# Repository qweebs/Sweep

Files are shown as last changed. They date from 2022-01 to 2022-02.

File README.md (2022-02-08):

# Sweep



<span>
  <a href="https://discord.gg/czXcTXbsgU">
    
  </a>
  
</span>

## What is sweep?

Sweep is a version of the more fabulous [Ferris](https://github.com/pierrechevalier83/ferris) by [Pierre Chevalier](https://github.com/pierrechevalier83/) that uses a daughter board like a promicro, elite-c, bit-c, nice!nano etc. instead of using onboard components.

## What are the different types?

| Device | Bluetooth Support<sup>[1]</sup> | On/Off Switch | Reversible PCB | Choc V1 | Choc V2 | Choc Mini | MX & Alps | Choc Spacing<sup>[2]</sup> | Tenting<sup>[3]</sup> |
| :--- | :---: | :---: | :---: | :---: | :---: | :---: | :---: | :---: | :---: |
| Sweep2.x | ✔ | ✔ | | ✔ | | | | ✔ | ✔ |
| Sweep Bling MX | ✔ | ✔ | ✔ | | | | ⚠<sup>[4]</sup> | | ✔ |
| Sweep High | ✔ | ✔ | | ✔ | ✔ | | ✔ | | ✔ |
| Sweep Half Swept  | ✔ | ✔ | ✔ | ✔ | | | | ✔ | ✔ |
| Sweep Compact Low | ✔ | | ✔ | | | ✔ | | ✔ | |

*<sup>[1]</sup> It simply means that it supports the nice!nano. An on/off switch is recommended for bluetooth*  
*<sup>[2]</sup> Choc spaced boards have the switches in a tighter grid. This provides a better final look but is only compatible with some choc keycaps (e.g. MBK)*  
*<sup>[3]</sup> Supports splitkb's [tenting puck](https://splitkb.com/products/tenting-puck?_pos=1&_psq=tenting%20&_ss=e&_v=1.0)*  
*<sup>[4]</sup> MX + kailh hotswap ONLY. Alps are NOT supported*  

* Sweep2 - Recommended Choc v1 board with all the features.
* Sweep Bling MX - An MX only Sweep that features Kailh's hotswap sockets and a stacked case.
* Sweep High - Same as the Sweep2 but trades choc spacing for compatibility with more switches and keycaps.
* Sweep Half Swept - Half of a Sweep2 with double pro-micro footprint (letting you avoid having one daughter-board flipped upside-down)
* Sweep Compact Low - The only version that supports Choc minis.

## Components list

To build and use a Sweep you will need:

* 1x PCB Kit
* 2x promicro compatible boards or 2 nice!nanos.
* 34 switches of a compatible type (refer to the compatibility table)
* 34 keycaps
* 2x reset switches (optional; [B3U-1000P(M)](https://github.com/davidphilipbarr/Sweep/issues/20))
* Some little rubber feet/bumpers
* 2x power switches (optional if supported; MSK 12C02)
* 1x TRRS (not TRS!) cable (wired build only)
* 2x TRRS Jack [PJ-320A] (wired build only)
* 1 USB Cable (depends on your micro-controller choice)

## How do I make this thing?

<a href="https://www.youtube.com/watch?v=fBPu7AyDtkM" target="_blank">
  
</a>

## Firmware

The firmware can be found [with the Ferris  firmware as part of QMK](https://github.com/qmk/qmk_firmware/tree/master/keyboards/ferris/sweep).

Firmware for zmk and bluemicro_ble is called ["Cradio"](https://zmk.dev/docs/hardware/).

## Who made this?

* [Pierre Chevalier](https://github.com/pierrechevalier83)
* [David Barr](https://github.com/davidphilipbarr)
* [Ibnu Daru Aji](https://github.com/ibnuda/)
* [Duccio](https://github.com/duckyb)

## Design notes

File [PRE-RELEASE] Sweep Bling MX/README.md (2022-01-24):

# <span style="color: #FFC400; font-weight: 600"> ⚠ WARNING! PRE-RELEASE!  ⚠</span>
## This device is currently in pre-release phase. <br> As such, it has not yet been tested and subject to changes. <br> Please keep this in mind if you wish to build it.

After being reported as functional it will receive a new stable release.

# Sweep Bling MX
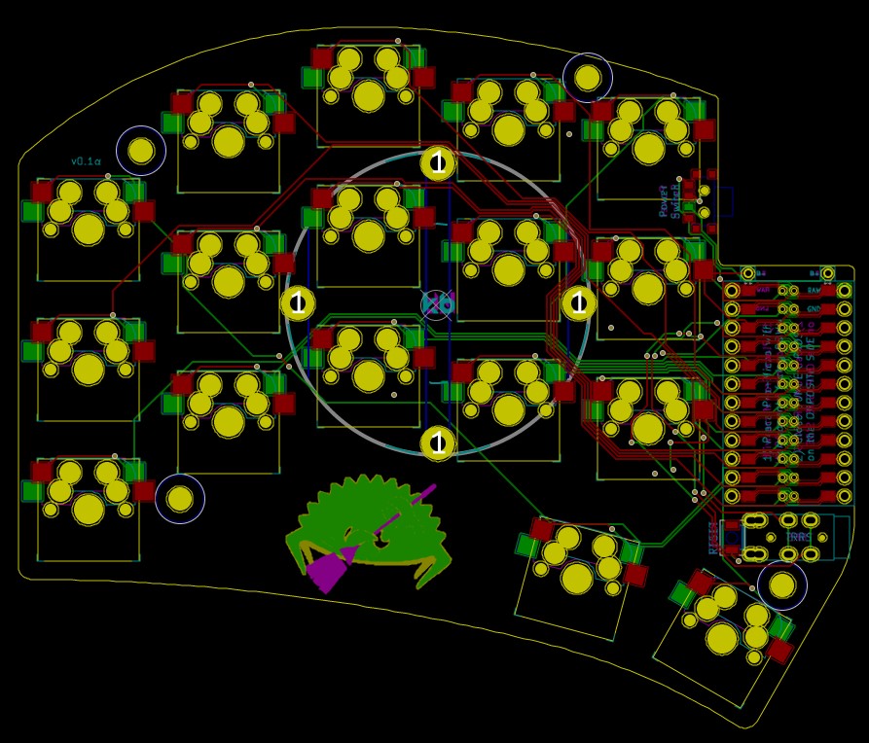
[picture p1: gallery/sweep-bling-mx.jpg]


This version of the Sweep features MX Switches support (exclusively) with hotswap sockets. As well as tenting support.

It also features mouting holes for a stacked case. You can find the switch plate and bottom plate files in the relative folders.

The bottom plate is also compatible with tenting, you can break away the middle section to allow installation of the puck.

## Ordering The PCB

To order the PCB the following settings are recommended<sup>1,2</sup>: 

|Detail|Value|
|---|---|
|Gerber file|`sweep_bling_mx_gerber.zip`|
|Base material|FR-4|
|Layers|2|
|Dimension|95.15mm x 229.54mm|
|Different design|1|
|Delivery format|Single PCB|
|PCB thickness|1.6mm|
|PCB color|(Personal preference)|
|Silkscreen|(Personal preference)|
|Surface finish|(Personal preference)|
|Outer copper weight|1oz|
|Gold Fingers|No|
|Confirm production file|No|
|Castellated holes|No|
|Remove order number|Yes|

1: Settings are for [JLCPCB](https://jlcpcb.com/), but could work for other manufacturers.

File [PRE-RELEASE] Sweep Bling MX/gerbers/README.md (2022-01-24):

| Bottom plate | PCB | Switch Plate |
| --- | --- | --- |
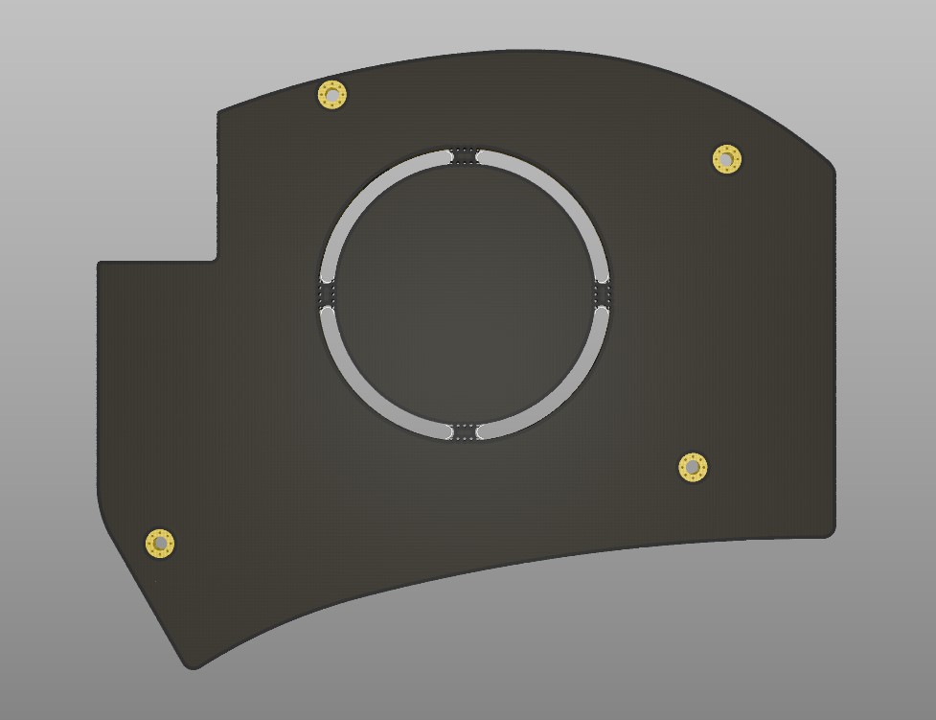
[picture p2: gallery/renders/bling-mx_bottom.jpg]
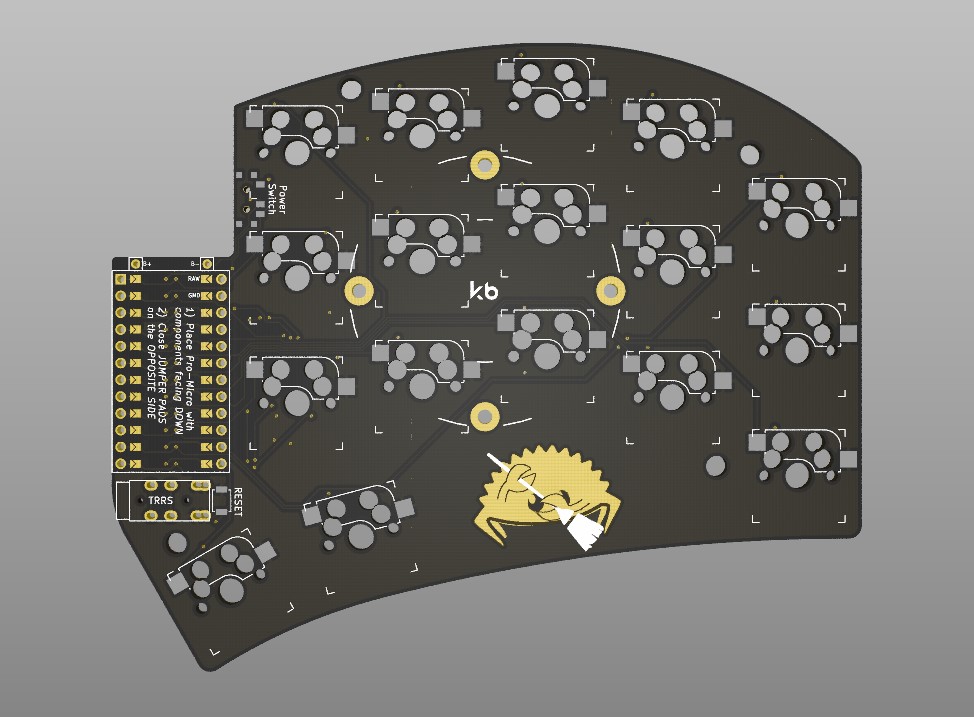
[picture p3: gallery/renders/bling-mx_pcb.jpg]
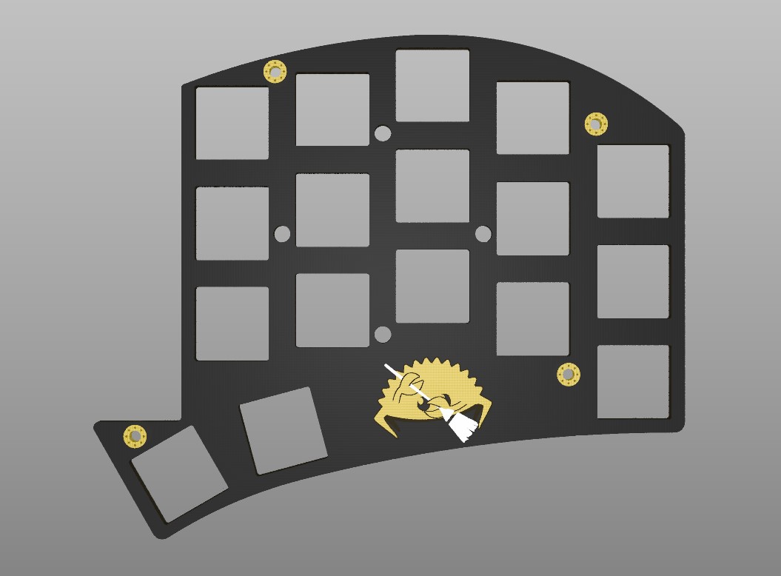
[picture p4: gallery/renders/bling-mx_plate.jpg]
|  |  |  |

# Notes:

- **DRILL TIME FEE**: When ordering PCBs with complex shapes like the switch plate and bottom plate, it is possible that the factory will ask for additional fees.

# PCB Hardware Kit (for both sides)
## Required
- 1x PCB Kit
- 2x promicro compatible boards or nice!nanos
- 34 MX switches
- 34 Kailh hotswap sockets
- 34 keycaps

### Optional:
- 2x Battery (required only for wireless; 301230 / 301228)
- 2x Power switches (recommended for wireless; MSK 12C02)
- 2x reset switches ([B3U-1000P(M)](https://github.com/davidphilipbarr/Sweep/issues/20))

# Case Hardware Kit (for both sides)

## Required:  
- 16x M2 Screws
- 8x M2 Spacers. (Max diameter: 3mm, Length: 6-8mm)
- 8-12x Silicone feet stickers

### Optional:
- 2x Splitkb tenting puck
- 2x Manfrotto MP3-BK tripods

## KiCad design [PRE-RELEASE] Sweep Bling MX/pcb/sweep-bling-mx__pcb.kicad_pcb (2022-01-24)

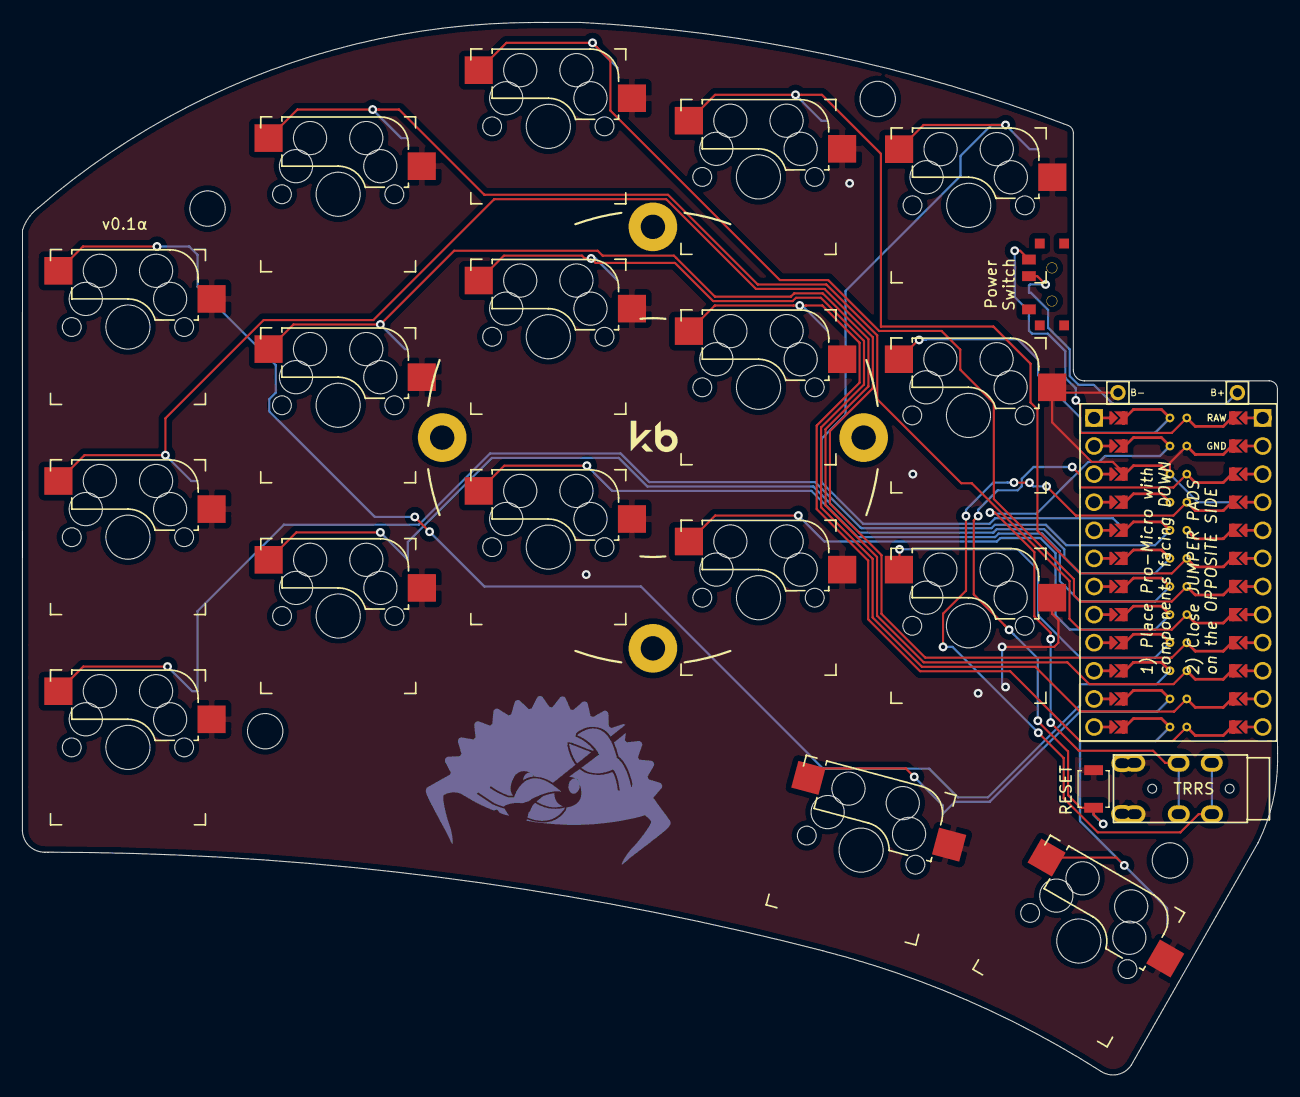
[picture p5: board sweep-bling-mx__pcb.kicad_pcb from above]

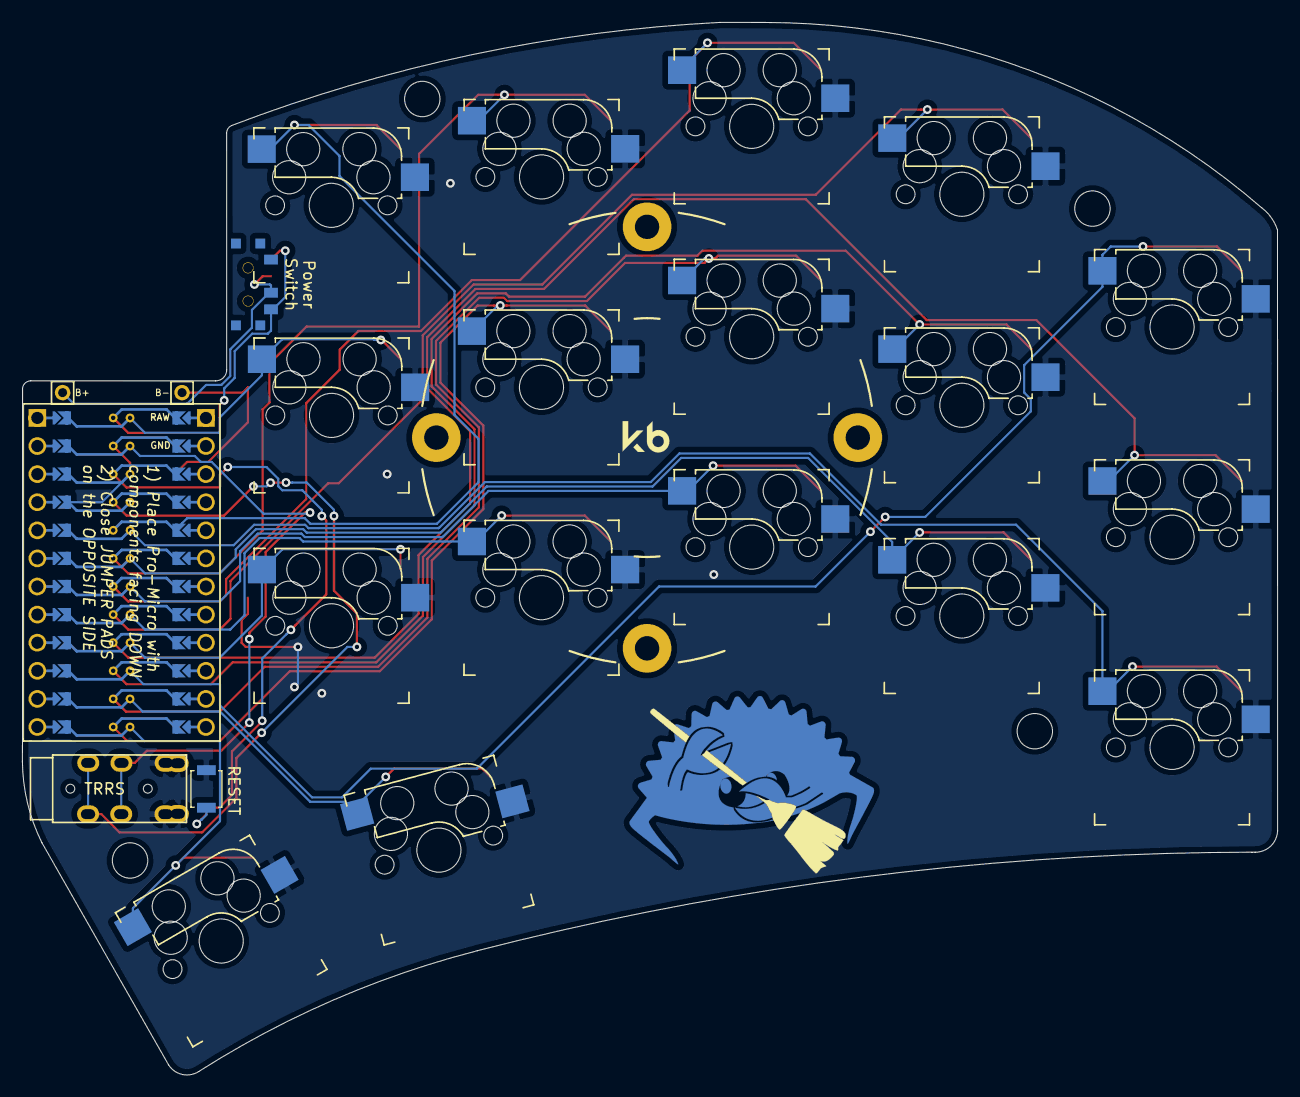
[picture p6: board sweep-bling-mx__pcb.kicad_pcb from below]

Board: 2 copper layers, 113.5 x 95.2 mm, 29 parts (2 on the bottom side), 23 nets.

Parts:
Bat+r1: MountingHole_Pad; 1pin_conn
BatGND1: MountingHole_Pad; 1pin_conn
J2: AudioJack4dpb; TRRS-PJ-DPB2
Mounting 01, Mounting 02, Mounting 03, Mounting 04: MountingHole_3.2mm_M3
RST_B: SW_Push; SW_SPST_B3U-1000P
RST_F: SW_Push; SW_SPST_B3U-1000P
SW2, SW3, SW4, SW5, SW6, SW8, SW9, SW10, SW11, SW12, SW14, SW15, SW16, SW17, SW18, SW20, SW21: SW_Push; Kailh_socket_MX_reversible_sameside
SW_POWERR1: SW_SPDT; SPDT_C128955
SW_POWERR_BK: SW_SPDT; SPDT_C128955r
U1: ProMicro-kbd; ProMicro_facedown

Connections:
BT+_r: Bat+r1.1, SW_POWERR1.2, SW_POWERR_BK.2
Switch1: SW2.1, U1.10
Switch2: SW3.1, U1.17
Switch3: SW4.1, U1.18
Switch4: SW5.1, U1.19
Switch5: SW6.1, U1.20
Switch6: SW8.1, U1.16
Switch7: SW9.1, U1.15
Switch8: SW10.1, U1.14
Switch9: SW11.1, U1.13
Switch10: SW12.1, U1.1
Switch11: SW14.1, U1.5
Switch12: SW15.1, U1.6
Switch13: SW16.1, U1.7
Switch14: SW17.1, U1.8
Switch15: SW18.1, U1.9
Switch16: SW21.1, U1.11
Switch17: SW20.1, U1.12
Switch18: J2.R1, U1.2
gnd: BatGND1.1, J2.S, J2.T, RST_B.1, RST_F.1, SW2.2, SW3.2, SW4.2, SW5.2, SW6.2, SW8.2, SW9.2, SW10.2, SW11.2, SW12.2, SW14.2, SW15.2, SW16.2, SW17.2, SW18.2, SW20.2, SW21.2, U1.3, U1.4, U1.23
raw: SW_POWERR1.3, SW_POWERR_BK.3, U1.24
reset: RST_B.2, RST_F.2, U1.22
vcc: J2.R2, U1.21

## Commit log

2022-01-24 Qweebs: remote the rust crab
    [sweepv2.1.kicad_pcb]
2022-02-08 remove switch references
    [sweepv2.1-B_Cu.gbr, sweepv2.1-B_Mask.gbr, sweepv2.1-B_Paste.gbr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]
